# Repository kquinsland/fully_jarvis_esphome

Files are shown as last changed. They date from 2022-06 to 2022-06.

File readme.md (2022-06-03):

# Jarvis ESPHome

This is an extension / port of the initial reverse engineering work done by [@phord](https://github.com/phord) for the [`Jarvis`](https://github.com/phord/Jarvis) repo.
Rather than build everything from scratch, I have ported most of the functionality to an ESPHome component.

**Note:** You almost certainly should not use this ESPHome component! Thanks to [@maraid](https://github.com/maraid), more of the [UART has been reverse engineered](https://github.com/maraid/Jarvis#technical-notes). This means that the PCB is out of date and can be re-factored to simply interface with the desk via UART. This theoretically also means that ESPHome can control more aspects of the desk more precisely with fewer wires and a simpler software implementation!

## ESPHome Component

I am not a full time C++ programmer so the code almost certainly does look like a bad copy/paste job.
That's because it largely is! I found a few different "similar" projects and modeled my code off of those.

Details on how to use the custom component with ESPHome can be found in [components/fully_jarvis_cb2c](components/fully_jarvis_cb2c).

## PCB

Inspired by [this](https://github.com/phord/Jarvis/discussions/18) thread, I created a simple PCB to interface with the desk control / motor driver.
I used a more capable ESP32 module specifically so I could drive some RGBWW LED strips as well.

See the [cad](cad/readme.md) folder for the KiCad files.

The (mostly populated) PCB looks like this:

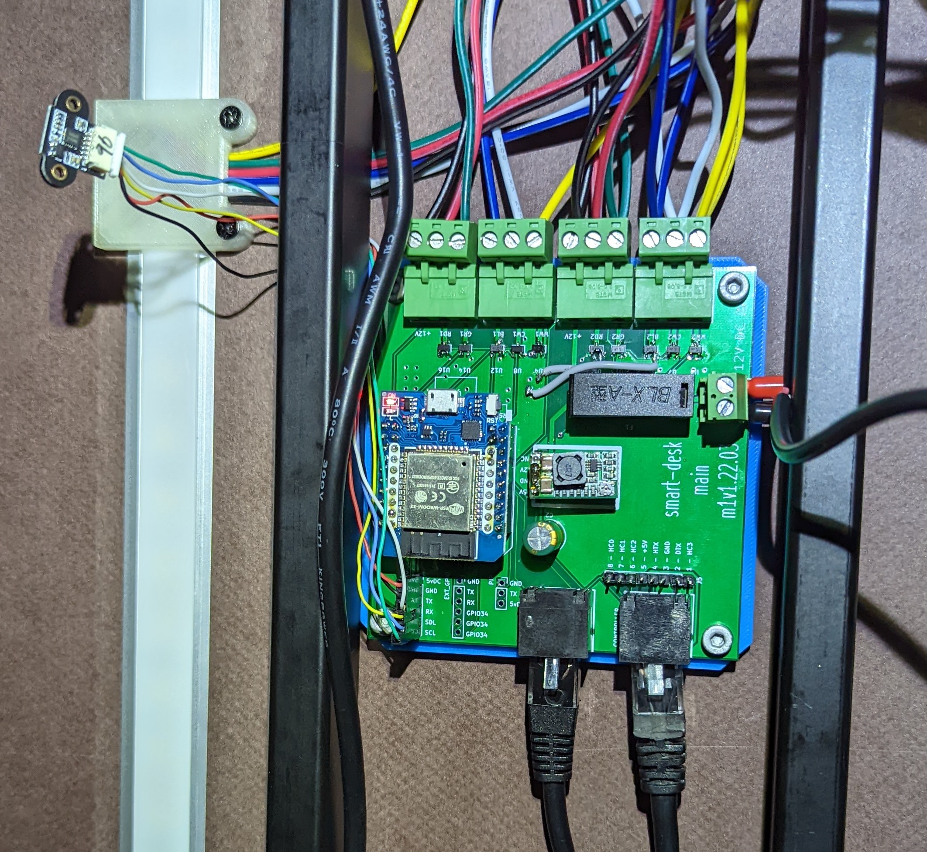
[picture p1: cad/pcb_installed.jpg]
pcb-installed


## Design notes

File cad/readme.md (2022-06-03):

# smart-desk-pcb

If you want to edit the pcb, the KiCad 6 files are included subject to [the license terms](../LICENSE.md).

The ESP32 module comes from [this](https://github.com/r0oland/ESP32_mini_KiCad_Library) library. Thanks to [r0oland](https://github.com/r0oland) for that library!

## BOM

The primary components on the PCB are:

- [D1 Mini style ESP32 chip](https://www.aliexpress.com/item/2251832633593063.html)
- [Configurable DC Buck converter module](https://www.aliexpress.com/item/32833398811.html). This steps the 12V dc from the KVM power supply down to the 5V for the ESP32 module.
- [RJ45 Jack (LCSC: C385834)](https://lcsc.com/product-detail/Ethernet-Connectors-Modular-Connectors-RJ45-RJ11_Ckmtw-Shenzhen-Cankemeng-R-RJ45R08P-A004_C385834.html). Footprint for this should be included in `jlcpcb.kicad_sym`. Two of theses for easy connection to the Jarvis remote/motor-controller.
- 2x5 ct [Diodes Incorporated DMN1019USN-7 (LCSC: C145103)](https://lcsc.com/product-detail/MOSFETs_Diodes-Incorporated-DMN1019USN-7_C145103.html). I had these handy and with the current ship shortage, it didn't seem worth th effort to try to source better ones. These are optional if you don't want the LED portion of the PCB.
- [Fuse holder (LCSC:C3131)](https://lcsc.com/product-detail/Fuse-Holders_Xucheng-Elec-C3131_C3131.html). Jump this out at your own risk!

There are some additional headers on the PCB for some optional components:

- PIR sensor (wired to ESP `gpio39`). I ended up not using this as I already have sufficient presence detection through other sensors placed around my home.
- An i2c based LIDAR sensor [`tof10120`](https://esphome.io/components/sensor/tof10120.html)) which I am using to measure distance from the desk to chair/person. Inclusion of this sensor was inspired by [this](.https://www.thouters.be/Standingstats.html) post from `Thomas Langewouters`.

## gerber

If you want to make zero changes, the [gerber files are included](./exports/2022-03.26.zip) and are subject to [the license terms](../LICENSE.md).

**Note**: There is a _small_ 'bug' with the v1 PCB: some of the MOSFETS do not have a connection to the ground plain. No, I don't know how this passed DRC. Fortunately, the fix is pretty easy: two small bodge wires connecting the GND pin from `U11` and `U15` to vias which connect to the ground plane.

pcb-installed-with-bodge-wires

**Note:** the two grey wires next to the fuse holder.

The gerber files / KiCad project are set up for use with JLCPCB but probably would work as-is with other PCB fab houses, too.

## Enclosure

I have included a STEP file export of the v1 PCB should you need it for PCB mounting hole locations or similar.

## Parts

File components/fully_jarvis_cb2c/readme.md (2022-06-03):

# ESPHome component

Below is a representative example config based on the one I use. I have included most of my `# TODO: ...` and similar notes made during the development / reverse engineering process for completion.

If not using the PCB with support for 10 PWM channels, you can safely remove the `light:` components and the related `output` components.

```yaml
esphome:
  # Note: this will be the hostname that device request during the DHCP dance... but appears to be broken on ESP32 devices
  # See: https://github.com/esphome/issues/issues/125
  name: ${hostname}
  platform: ESP32
  board: mhetesp32minikit

# Enable logging
logger:
  # Set to DEBUG for loads of messages about uart packets
  ##
  level: INFO
  # We prevent the constant stream of "[E][uart:015]: Reading from UART timed out at byte 0!" messages"
  logs:
    uart: NONE

# See: https://esphome.io/components/external_components.html
##
external_components:
  - source:
      type: git
      url: https://github.com/kquinsland/fully_jarvis_esphome/components/
    components:
      - fully_jarvis_cb2c

# Expose a raw number entry so we can assign an arbitrary height (within some precision limits; see c++ code)
number:
  - platform: template
    id: int_desk_height
    name: Desk Height
    icon: "mdi:human-male-height-variant"
    entity_category: config
    unit_of_measurement: cm
    # The 3 stage model goes from 24.5 inches to 50 inches (without top) which is 62-127cm
    min_value: 63
    # Likewise, we don't want to linger for more than 30s
    max_value: 127
    # Desk measures height accurate to ~1mm
    step: .1
    # Called when HA sets the number
    set_action:
      then:
        - logger.log:
            format: "Desk Height Set to %.1f"
            args: [x]
        - lambda: |-
            // goto_height() needs at most 1 decimal
            // multiply whatever the user gives us by 10 so the single decimal point is to the left of the decimal
            // then turn it into an int to drop all decimal
            double h = (int) (x*10);
            // and shift back to get the single decimal
            h = h /10;
            id(desk).goto_height(h);

  # We expose buttons to HA to exactly mimic the front panel
  - platform: template
    id: inp_preset_1
    name: "Desk Height Preset 1"
    icon: "mdi:numeric-1-box"
    entity_category: "config"
    on_press:
      then:
        - logger.log:
            format: "Preset selected: %u"
            args: ["1"]
        - lambda: |-
            id(desk).goto_preset(1);
  - platform: template
    id: inp_preset_2
    name: "Desk Height Preset 2"
    icon: "mdi:numeric-2-box"
    entity_category: "config"
    on_press:
      then:
        - logger.log:
            format: "Preset selected: %u"
            args: ["2"]
        - lambda: |-
            id(desk).goto_preset(2);
  - platform: template
    id: inp_preset_3
    name: "Desk Height Preset 3"
    icon: "mdi:numeric-3-box"
    entity_category: "config"
    on_press:
      then:
        - logger.log:
            format: "Preset selected: %u"
            args: ["3"]
        - lambda: |-
            id(desk).goto_preset(3);

  - platform: template
    id: inp_preset_4
    name: "Desk Height Preset 4"
    icon: "mdi:numeric-4-box"
    entity_category: "config"
    on_press:
      then:
        - logger.log:
            format: "Preset selected: %u"
            args: ["4"]
        - lambda: |-
            id(desk).goto_preset(4);

# This works! If i keep clicking it, the remote will activate. The buttons come on immediately, screen is blank
#   but the remote appears to have a failsafe because after a few seconds, the "fully" logo shows up and stays
#   on the screen until the wake packet stops getting sent
##
  # - platform: template
  #   id: inp_wake
  #   name: "Wake Remote"
  #   icon: "mdi:arrow-down-bold-box"
  #   entity_category: "config"
  #   on_press:
  #     then:
  #       - lambda: |-
  #           //id(desk).do_null();
  #           id(desk).do_wake();

# See: https://esphome.io/components/light/rgbww.html
light:
  - platform: rgbww
    name: "Lights Channel 1"
    id: led_center
    red: pwm_rd_1
    green: pwm_gn_1
    blue: pwm_bu_1
    cold_white: pwm_cw_1
    warm_white: pwm_ww_1
    cold_white_color_temperature: 6500 K
    warm_white_color_temperature: 2400 K
    # We tell HA that we support a few built in effects
    # See: https://esphome.io/components/light/index.html#light-effects
    effects:
      - pulse:
      - random:
      - strobe:

##
# In PCB Bring up, there is something wrong with the BLUE and RED channels on the second bank.
# Somehow, there's no ground connection so the mosfets are ineffective. I was able to fix this with bodge wires
#   for the BL2 and RD2 channels
###
  - platform: rgbww
    name: "Lights Channel 2"
    id: led_side
    red: pwm_rd_2
    green: pwm_gn_2
    blue: pwm_bu_2
    cold_white: pwm_cw_2
    warm_white: pwm_ww_2
    cold_white_color_temperature: 6500 K
    warm_white_color_temperature: 2400 K
    # We tell HA that we support a few built in effects
    # See: https://esphome.io/components/light/index.html#light-effects
    effects:
      - pulse:
      - random:
      - strobe:

output:
  - platform: ledc
    id: pwm_rd_1
    pin: GPIO5

  - platform: ledc
    id: pwm_gn_1
    pin: GPIO12

  - platform: ledc
    id: pwm_bu_1
    pin: GPIO13

  - platform: ledc
    id: pwm_ww_1
    pin: GPIO00

  - platform: ledc
    id: pwm_cw_1
    pin: GPIO4

  - platform: ledc
    id: pwm_rd_2
    pin: GPIO25

  - platform: ledc
    id: pwm_gn_2
    pin: GPIO26

  - platform: ledc
    id: pwm_bu_2
    pin: GPIO27

  - platform: ledc
    id: pwm_ww_2
    pin: GPIO14

  - platform: ledc
    id: pwm_cw_2
    pin: GPIO23

  # I don't understand WHY, but we NEED to set up the GPIO here as outputs before calls to digital_write()
  #   in the custom component will work. Can also do this as template switch but this is cleaner.
  - platform: gpio
    id: out18
    pin: GPIO18
  - platform: gpio
    id: out19
    pin: GPIO19
  - platform: gpio
    id: out32
    pin: GPIO32
  - platform: gpio
    id: out33
    pin: GPIO33

# Testing the jarvis desk integration
# The remote/controller use 6 pins but only two of them are serial like
# @phord calls them DTX and HTX. I have called them the same
#   - DTX: Serial messages from controller to handset (remote)
#   - HTX: Serial messages from handset to controller (motor driver)
uart:
  # The ESP32 has 3 UART; 0 is programming / debugging, 1 is in use (flash) so we will use 2
  id: desk_uart
  # We want to impersonate the remote/handset by injecting via the HTX pin which is mapped to 17
  tx_pin: GPIO17
  # Likewise, if the motor controller sends anything to the remote, we _also_ want to hear it.
  rx_pin: GPIO16
  # bog standard 9600 8n1
  baud_rate: 9600

# Load up __init.py__
fully_jarvis_cb2c:
    id: desk
    # This is read from the UART
    height:
      name: "Desk Height"
    # The GPIO we manipulate to simulate pressing buttons
    hc0_pin: GPIO18
    hc1_pin: GPIO19
    hc2_pin: GPIO32
    hc3_pin: GPIO33

```

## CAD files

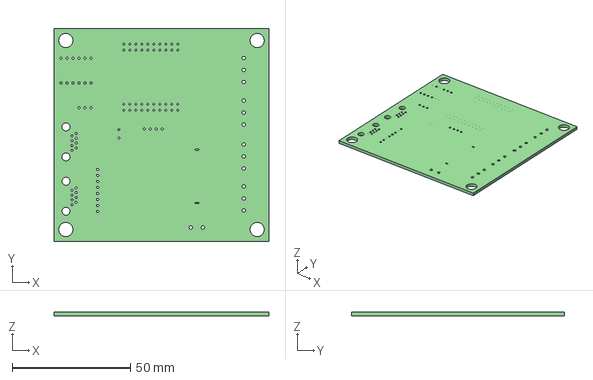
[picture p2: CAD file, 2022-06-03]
cad/smart-desk-pcb.step
91.0 x 90.0 x 1.60 mm

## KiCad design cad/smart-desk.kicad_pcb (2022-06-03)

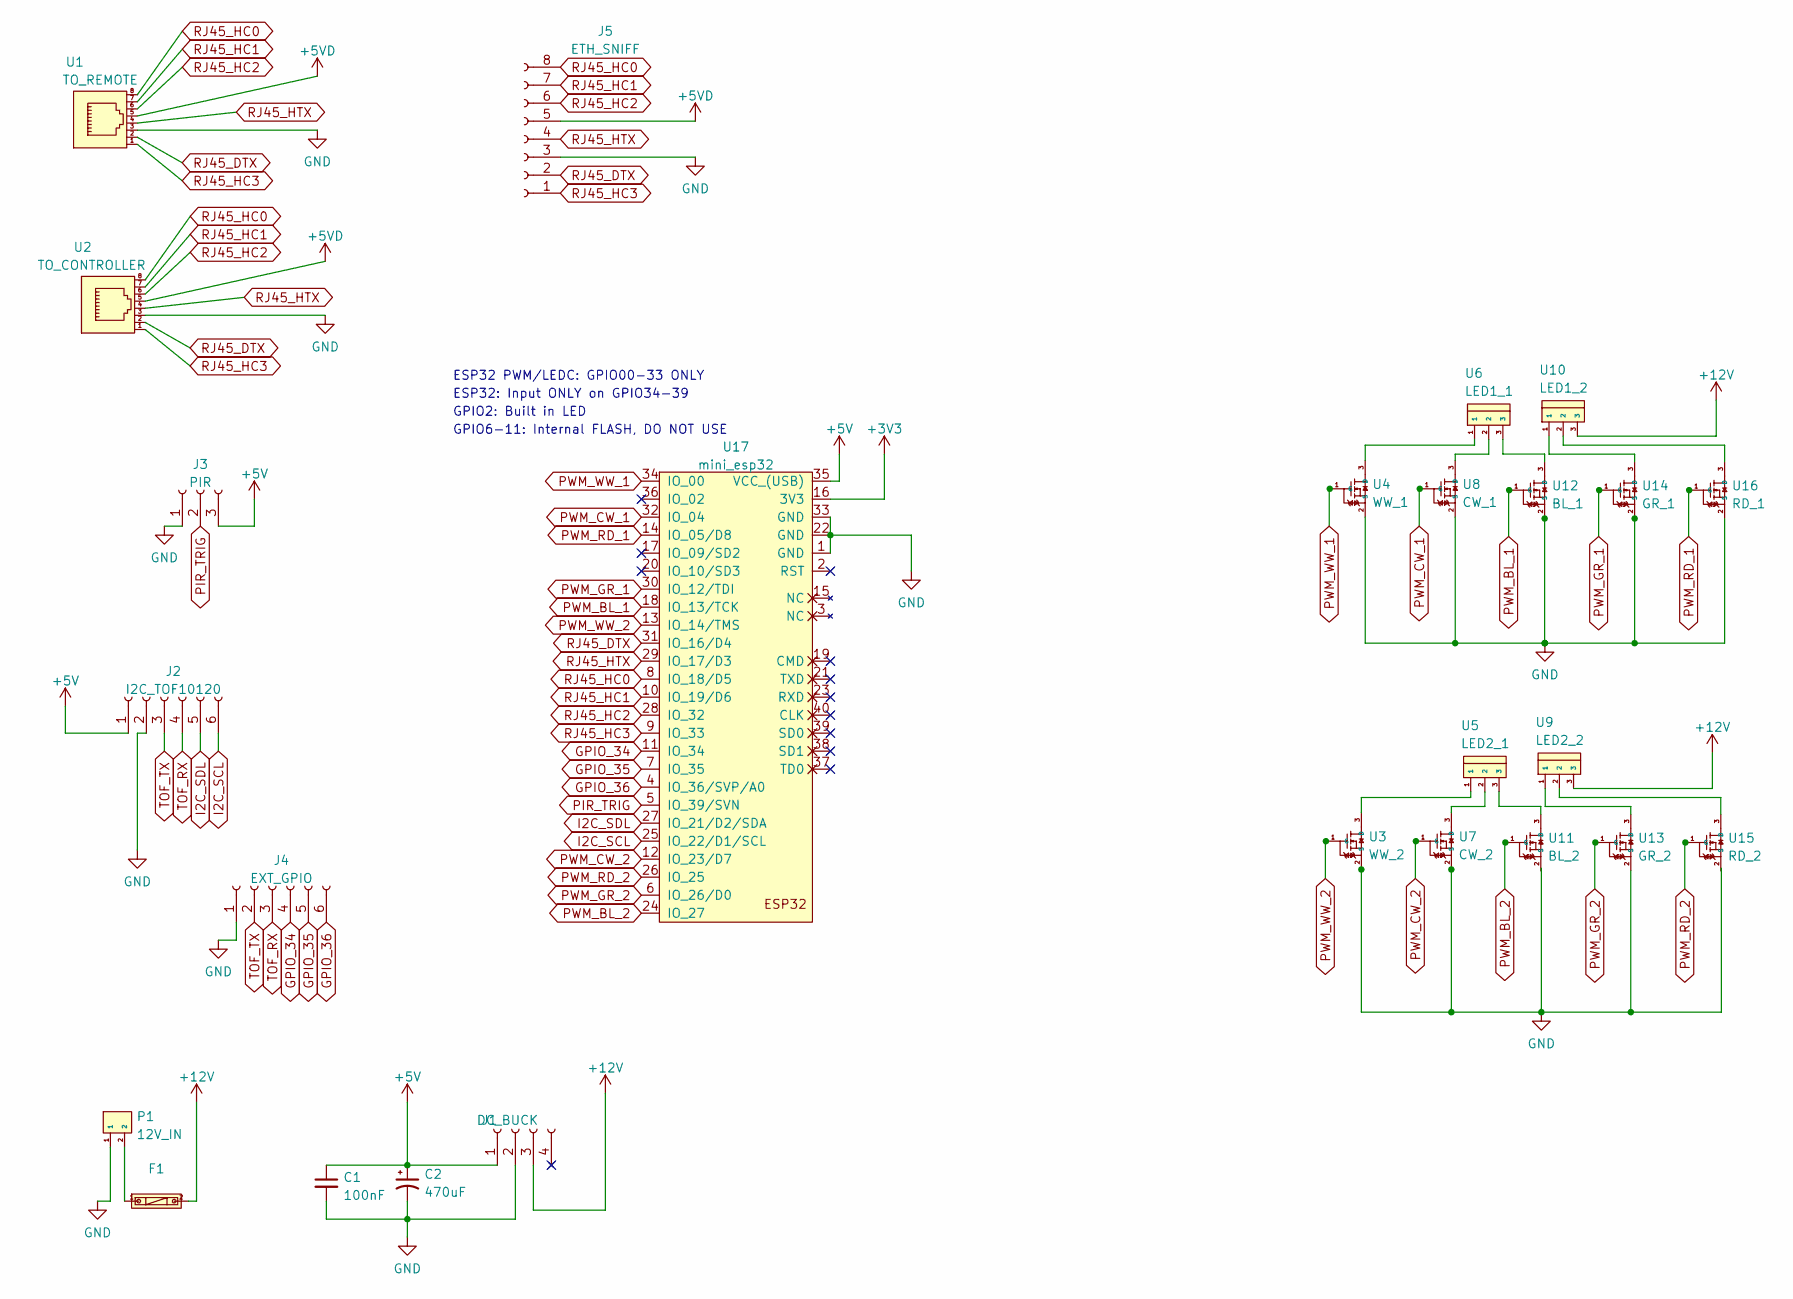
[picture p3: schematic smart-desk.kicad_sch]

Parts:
C1: 100nF; C_0805_2012Metric
C2: 470uF; C_Radial_D8.0mm_H11.5mm_P3.50mm
F1: 5x20_BLX-Atype_Fuse_holder_XC-7; C3131
J1: DC_BUCK; PinSocket_1x04_P2.54mm_Vertical
J2: I2C_TOF10120; PinSocket_1x06_P2.54mm_Vertical
J3: PIR; PinSocket_1x03_P2.54mm_Vertical
J4: EXT_GPIO; PinSocket_1x06_P2.54mm_Vertical
J5: ETH_SNIFF; PinSocket_1x08_P2.54mm_Vertical
P1: 12V_IN; WJ129V-5.0-2P
U1: TO_REMOTE; R-RJ45R08P-A004
U2: TO_CONTROLLER; R-RJ45R08P-A004
U3: WW_2; DMN1019USN-7
U4: WW_1; DMN1019USN-7
U5: LED2_1; 1757255
U6: LED1_1; 1757255
U7: CW_2; DMN1019USN-7
U8: CW_1; DMN1019USN-7
U9: LED2_2; 1757255
U10: LED1_2; 1757255
U11: BL_2; DMN1019USN-7
U12: BL_1; DMN1019USN-7
U13: GR_2; DMN1019USN-7
U14: GR_1; DMN1019USN-7
U15: RD_2; DMN1019USN-7
U16: RD_1; DMN1019USN-7
U17: mini_esp32; ESP32_mini

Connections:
+3V3: U17.16 (3V3)
+5VD: J5.5, U1.5, U2.5
+12V: F1.2, J1.3, U9.3, U10.3
GND: C1.2, C2.2, J1.2, J2.2, J3.1, J4.1, J5.3, P1.1, U1.3, U2.3, U3.2 (S), U4.2 (S), U7.2 (S), U8.2 (S), U12.2 (S), U13.2 (S), U14.2 (S), U16.2 (S), U17.1 (GND), U17.22 (GND), U17.33 (GND)
GPIO_34: J4.4, U17.11 (IO_34)
GPIO_35: J4.5, U17.7 (IO_35)
GPIO_36: J4.6, U17.4 (IO_36/SVP/A0)
I2C_SCL: J2.6, U17.25 (IO_22/D1/SCL)
I2C_SDL: J2.5, U17.27 (IO_21/D2/SDA)
unnamed: F1.1, P1.2
unnamed: U3.3 (D), U5.1
unnamed: U4.3 (D), U6.1
unnamed: U5.2, U7.3 (D)
unnamed: U6.2, U8.3 (D)
unnamed: U10.1, U14.3 (D)
unnamed: U10.2, U16.3 (D)
unnamed: U5.3, U11.3 (D)
unnamed: U6.3, U12.3 (D)
unnamed: U9.1, U13.3 (D)
unnamed: U9.2, U15.3 (D)
PIR_TRIG: J3.2, U17.5 (IO_39/SVN)
PWM_BL_1: U12.1 (G), U17.18 (IO_13/TCK)
PWM_BL_2: U11.1 (G), U17.24 (IO_27)
PWM_CW_1: U8.1 (G), U17.32 (IO_04)
PWM_CW_2: U7.1 (G), U17.12 (IO_23/D7)
PWM_GR_1: U14.1 (G), U17.30 (IO_12/TDI)
PWM_GR_2: U13.1 (G), U17.6 (IO_26/D0)
PWM_RD_1: U16.1 (G), U17.14 (IO_05/D8)
PWM_RD_2: U15.1 (G), U17.26 (IO_25)
PWM_WW_1: U4.1 (G), U17.34 (IO_00)
PWM_WW_2: U3.1 (G), U17.13 (IO_14/TMS)
RJ45_DTX: J5.2, U1.2, U2.2, U17.31 (IO_16/D4)
RJ45_HC0: J5.8, U1.8, U2.8, U17.8 (IO_18/D5)
RJ45_HC1: J5.7, U1.7, U2.7, U17.10 (IO_19/D6)
RJ45_HC2: J5.6, U1.6, U2.6, U17.28 (IO_32)
RJ45_HC3: J5.1, U1.1, U2.1, U17.9 (IO_33)
RJ45_HTX: J5.4, U1.4, U2.4, U17.29 (IO_17/D3)
TOF_RX: J2.4, J4.3
TOF_TX: J2.3, J4.2

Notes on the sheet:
ESP32 PWM/LEDC: GPIO00-33 ONLY
ESP32: Input ONLY on GPIO34-39
GPIO2: Built in LED
GPIO6-11: Internal FLASH, DO NOT USE

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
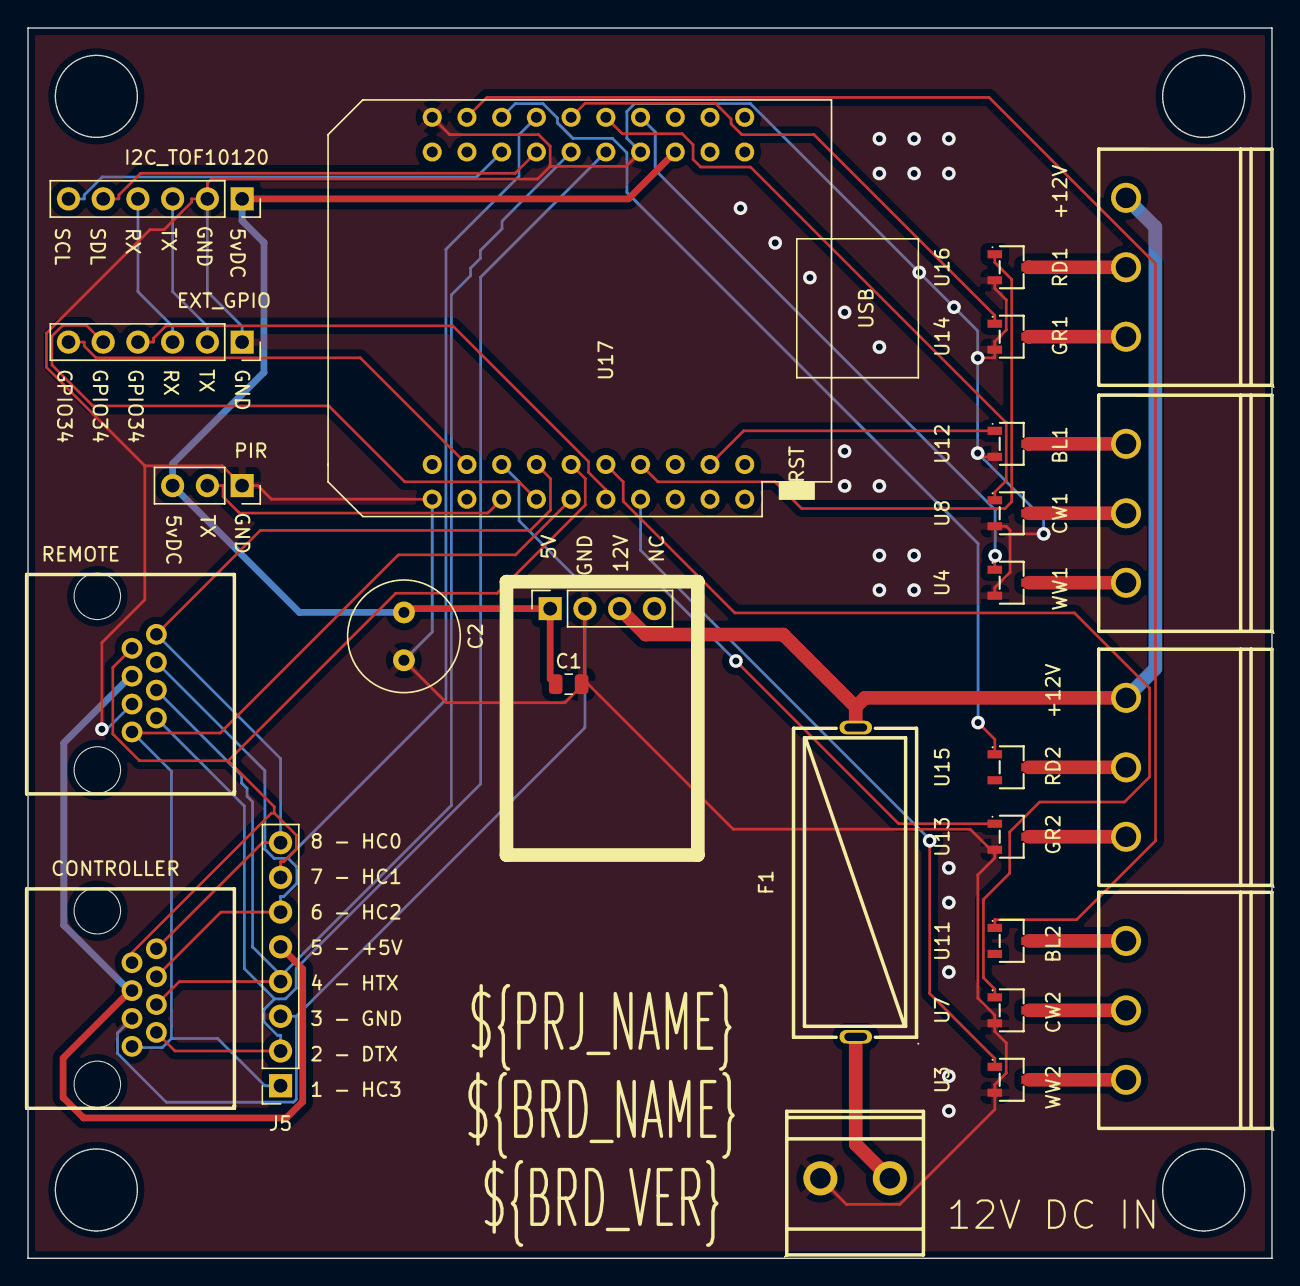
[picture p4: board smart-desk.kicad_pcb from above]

Board: 2 copper layers, 91.0 x 90.0 mm, 26 parts (0 on the bottom side), 39 nets.

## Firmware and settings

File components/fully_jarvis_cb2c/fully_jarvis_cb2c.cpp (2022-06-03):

#include <math.h> /* round, floor, ceil, trunc */

#include "fully_jarvis_cb2c.h"
#include "esphome/core/log.h"

namespace esphome
{
      namespace fully_jarvis_cb2c
      {

            static const char *TAG = "jarvis.2b2c";
            // In testing w/ oscilloscope, the remote pulls the various control lines down for ~150ms
            static const int btn_delay_time = 150;

            // It appears that the LONGEST possible packet is 9 bytes
            // See: https://github.com/phord/Jarvis#uart-protocol
            static const uint8_t JARVIS_PACKET_MAX_LEN = 9;

            // TODO: is there a setup call I can override?
            // At setup, I need to poke the desk to get it's current preset / units... etc
            void JarvisCB2CSensor::setup()
            {
                  // this->dump_config();
                  //  TODO: Might want to send WAKE 0x29 command to make sure the motor controller is alive
                  //  TODO: might want to see if there is a inquiry message to get the current settings rather than just SET them
                  //           e.g: 0x0E / UNITS is to SET the units... not to inquire what they are. It could be that this does not exist
                  //           and the motor never asks the remote what units it should be using.
                  //
                  //  I am reluctant to expose that functionality to HA because there could be some adverse effects. What happens if
                  //           ha -> esphome tells the motor to be in CM but the remote still thinks its in inches?
                  //////
                  // Default is to have all pins floating high; remote signals a button press by pulling low
                  if (this->hc0_pin != nullptr)
                        this->hc0_pin->digital_write(true);

                  if (this->hc1_pin != nullptr)
                        this->hc1_pin->digital_write(true);

                  if (this->hc2_pin != nullptr)
                        this->hc2_pin->digital_write(true);

                  if (this->hc3_pin != nullptr)
                        this->hc3_pin->digital_write(true);

                  ESP_LOGD(TAG, "Setup: Pins should be high!");
            }

            /*
                  Called every ~16ms. We read bytes until we have a valid packet
            */
            void JarvisCB2CSensor::loop()
            {
                  uint8_t response[JARVIS_PACKET_MAX_LEN];
                  uint8_t peeked;

                  // 0x7E is the End of Message byte
                  while (this->available())
                  {
                        // Get the byte
                        this->peek_byte(&peeked);
                        // ESP_LOGD(TAG, "peeked: %x \t %u", peeked, peeked);

                        if (peeked != 0x7e)
                        {
                              this->read();
                              // There's nothing else for us to do so bail early
                              return;
                        }
                        else
                        {
                              // We still read the byte for completeness then break out of the while loop to read/process the packet we have.
                              this->read();
                              ESP_LOGD(TAG, "EOM");
                              break;
                        }
                  }

                  bool read_success = read_array(response, JARVIS_PACKET_MAX_LEN);
                  if (!read_success)
                  {
                        // Don't need this as there will be plenty of:
                        //          Reading from UART timed out at byte 0!
                        // in the logs
                        ////
                        // ESP_LOGE(TAG, "Failure reading UART bytes!");
                        status_set_warning();

                        // Even though we didn't get anything from the UART, we still should move, if needed
                        this->_adjust_height();
                        return;
                  }
                  // Now we validate the packet
                  if (!this->verify_cb2c_checksum_(response))
                  {
                        ESP_LOGW(TAG, "Checksum didn't match!");
                        status_set_warning();
                        return;
                  }

                  // Checksum is good! Extract the 'command' byte and dispatch
                  uint8_t pkt_type = response[2];
                  switch (pkt_type)
                  {
                  case 1:
                        /*
                              command 1: height report packet looks like this:

                                    [0] 0xf2         (242)
                                    [1] 0xf2         (242)
                                    [2] 0x1          (1)
                                    [3] 0x3          (3)
                                    [4] 0x1          (1)
                                    [5] 0x97         (151)
                                    [6] 0x3          (3)
                                    [7] 0x9f         (159)
                                    [8] 0x7e         (126)

                              There should be 3 params, the first two are the high/low bytes and the third has unknown purpose
                              See: https://github.com/phord/Jarvis#height-report
                        */
                        uint8_t height_hi = response[4];  // 0x01
                        uint8_t height_low = response[5]; // 0x97

                        // 0197 is 407 ... and the display says 40.7 on it!
                        this->current_pos_ = (height_hi << 8) + height_low;
                        ESP_LOGD(TAG, "height: %d", this->current_pos_);

                        // Raw input will be in tenths of $UNIT. EG 407 -> 40.7 inches
                        // _to_mm(407) => 1033.78
                        // 1033.78 * .001 = 1.03378
                        // We will let ESPHome do the truncation for us; we define 4 decimals of accuracy so
                        //   the reading will show as 1.0338m in HA. This is human friendly but still has enough
                        //   precision in it so user can do meter to mm conversion (for whatever reason...) and they'll
                        //   get something pretty accurate.
                        this->height_sensor_->publish_state(_to_mm(this->current_pos_) * .001);
                        break;
                  }

                  // If goto_height() has been called since we last ran
                  this->_adjust_height();
            }
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

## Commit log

2022-06-03 Add PCB readme
    and installed photo w/ bodge wires
    [smart-desk-pcb.step, smart-desk.kicad_pcb, smart-desk.kicad_sch]
2022-06-03 Add GERBER exports
    and update main readme to include pic
